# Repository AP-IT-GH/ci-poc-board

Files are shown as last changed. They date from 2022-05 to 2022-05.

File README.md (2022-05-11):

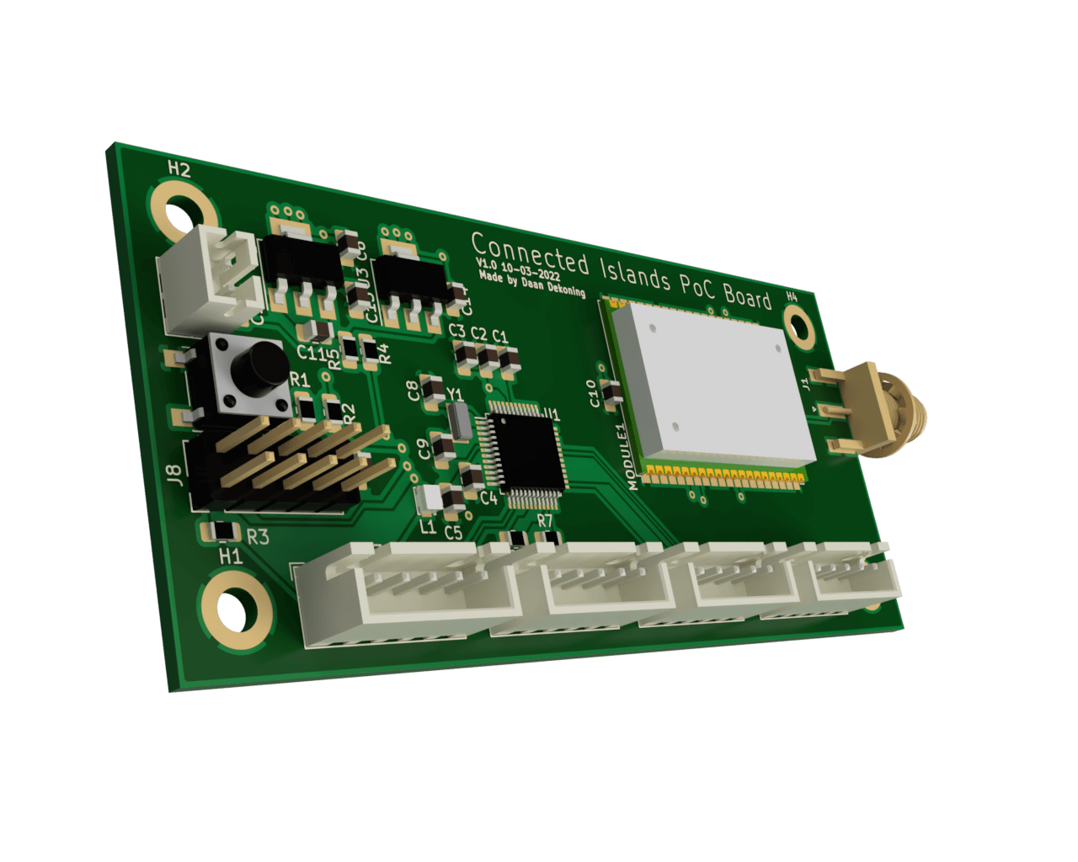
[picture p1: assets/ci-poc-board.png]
PCB


# Connected Island Proof of Concept Board

This board is used to gather data from many different sensors and send it over a LoRa network. 
The MCU on the board is an AT SAM D21 chosen because of it's low power capabilities and the extensive I/O options.
On board we have:
- 3 USART connection headers
- 1 I²C connection header
- 1 programming & debug connection
- RN2483 LoRaWAN module

The board can be powered with a voltage between 6.3V and 15V.

This document can be used to understand our reasoning behind certain choices and to learn how the board works. On the bottom we have a few improvements and suggestions for future versions.

The Bill of Materials to assemble the PCB can be found [here](./assets/bom/ibom.html) in HTML format.

## First Version

<figure>
<iframe src="https://myap84.autodesk360.com/shares/public/SH35dfcQT936092f0e434feaf45240fcc95f?mode=embed" width="1024" height="768" allowfullscreen="true" webkitallowfullscreen="true" mozallowfullscreen="true"  frameborder="0"></iframe>
<figcaption >Interactive 3D model of the PCB</figcaption>
</figure>

<figure>
Mindmap
<figcaption >Figure 1: Main Schematic</figcaption>
</figure>

<figure>
Mindmap
<figcaption >Figure 2: Power Regulators Schematic</figcaption>
</figure>

<figure>
Mindmap
<figcaption >Figure 3: RN2483 LoRaWAN module Schematic</figcaption>
</figure>

### Power Delivery

We are using a Li-Po 2 Cell battery and a LD1117 as 3.3V and 5V regulator

Li-Po 2 Cell: [Store](https://www.conrad.be/p/conrad-energy-lipo-accupack-74-v-2400-mah-aantal-cellen-2-20-c-softcase-xt60-1344133), [Datasheet](https://asset.conrad.com/media10/add/160267/c1/-/en/001344133SD01/veiligheidsvoorschriften-1344133-conrad-energy-lipo-accupack-74-v-2400-mah-aantal-cellen-2-20-c-sof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)

LD1117: [Store](https://www.conrad.be/p/stmicroelectronics-ld1117av33-spanningsregelaar-lineair-to-220ab-positief-vast-1-a-1184973), [Datasheet](https://asset.conrad.com/media10/add/160267/c1/-/en/001184973DS01/datablad-1184973-stmicroelectronics-ld1117av33-spanningsregelaar-lineair-to-220ab-positief-vast-1-a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)

The LD1117 IC's are connected according to "Figure 3. Application circuit (for fixed output voltages)". 1x 5V en 1x 3.3V.

The dropout voltage of these regulators is 1.05V if we're counting for a 500mAh load. to get an output voltage of 5V, the regulator needs an input voltage of 5V + 1.05V = 6.05V. Thus our battery voltage has to stay above that value.

ADC voltage divider for battery:

R1 = 10 kOhm; R2 = 4.7 kOhm

### AT SAMD 21 Schematic Checklist

Datasheet p1108-p1118

#### Power Supply Connections

- [x] Check L1 10µH footprint. (https://be.farnell.com/tdk/vls201612hbx-100m-1/inductor-10uh-20-0-79a-shld/dp/2455369 ) (https://www.farnell.com/datasheets/2608157.pdf )

The MCU has two DVVIO pins (pin17 en pin36), these are internally connected to each other so only pin17 is in use.

#### External Analog Reference Connections

Not necessary because we are not using any external analog references.

#### External Reset Circuit

EFT = electrical fast transients -> spark when pressing a button

We don't need this EFT Immunity Enhancement so we're using "Figure 45-4. External Reset Circuit Schematic".

#### Clocks and Crystal Oscillators

[Understanding the SAM D21 clocks](https://blog.thea.codes/understanding-the-sam-d21-clocks/)

We keep the option to use an external 32,768kHz clock free, when not in use it doesn't have to be soldered on the PCB.

- [Capacitor](https://be.farnell.com/multicomp/mc0805n180j500ct/cap-18pf-50v-5-c0g-np0-0805/dp/1759194): MC0805N180J500CT, 18 pF, 0805
- [Crystal](https://be.farnell.com/fox-electronics/fx135a-327/crystal-32-768khz-12-5pf-smd/dp/2064037): FX135A-327, 32.768 kHz, SMD

Connected according to: "Figure 45-9. External Real Time Oscillator with Load Capacitor".

`XIN32` and `XOUT32` are on the only available connections for SERCOM1 (PA00 en PA01) so SERCOM1 will not be used.

#### Programming and Debug Ports

Pull-up resistor on SWCLK!

We are using "Figure 45-12. 10-pin JTAGICE3 Compatible Serial Wire Debug Interface".

#### USB Interface

We are not using the USB interface.

### SERCOM Aansluiten

The used SERCOM pins of the SAM D21 got a `SERCOMx_PADn_y` label for easy reference on the scheme and PCB. The Atmel START configuration was used as a reference.

SERCOM-ALT [ref1](https://microchipsupport.force.com/s/article/SERCOM-muxing-on-SAM-D-L-C-devices), [ref2](https://learn.adafruit.com/using-atsamd21-sercom-to-add-more-spi-i2c-serial-ports/muxing-it-up)

| Use case | SERCOM  | Pins | Function |
| --- | --- | --- | --- |
| RN2384  | SERCOM0 | PA04, PA05, PA07 | TX, RX, <span style="text-decoration:overline">RESET</span> |
| USART_1 | SERCOM5 | PA22, PA23 | TX, RX |
| USART_2 | SERCOM2 | PA08, PA09 | TX, RX |
| USART_3 | SERCOM3 | PA16, PA17 | TX, RX |
| I2C_0 | SERCOM4 | PA12, PA13 | SDA, SCL |

> If the PA24 and PA25 pins are not connected, it is recommended to enable a pull-up on PA24 and PA25 through input GPIO mode. The aim is to avoid an eventually extract power consumption (<1mA) due to a not stable level on pad. The port PA24 and PA25 doesn't have Drive Strength option. (these are the USB pins). 

[ATSAMD D21 Datasheet](https://ww1.microchip.com/downloads/en/DeviceDoc/SAM-D21DA1-Family-Data-Sheet-DS40001882G.pdf)

### RN2483 LoRaWAN module

[RN2483 Datasheet](https://ww1.microchip.com/downloads/en/DeviceDoc/RN2483-Low-Power-Long-Range-LoRa-Technology-Transceiver-Module-DS50002346F.pdf) 

Reuse of symbol from the older AirQualitySensor project.

`PA6` who is connected to `RN2384_RESET` should always be HIGH. You can reset the RN2483 module by setting the pin LOW for a moment.

<u>Are we using `UART_CTS` and `UART_RTS` as a handshake mechanism?</u>: No

<u>Do we connect the Internal Program Pins with the 6-pin ICSP header on our PCB?</u>: No

We are using RFH for 868MHz communication.

> When routing RF paths, use proper strip lines with an impedance of 50 Ohm.

We are not using the GPIO pins of the module.

## Future Versions

Luckily, the first version of this board works. Of course we have a few remarks to make for future versions of this board. 
A short summary:
- More marks on the silkscreen explaining the pinout of headers
- A different battery connector
- Adding a USB port
- Placing components on the back

### Markings

The first version of the board doesn't show any markings for the pinout of the headers. The battery connector doesn't even have a polarity marking. 

### Battery Connector

The current battery connector is very small and not very useful. A specific new connector has not been chosen yet.

### USB Port

We think that a USB port on the PCB would be very useful. There exists a bootloader for the ATSAMD 21 that enables users to program the board with CircuitPython. This might make the board easier to use. Other bootloaders enable the use of the Arduino IDE instead of Microchip Studio. 
Right now the board can only be programmed with a J-LINK or Atmel ICE programmer. 

### Components on the Back

Right now every component on the board is positioned on the front. We think a lot of space can be saved by placing some SMD components on the back.

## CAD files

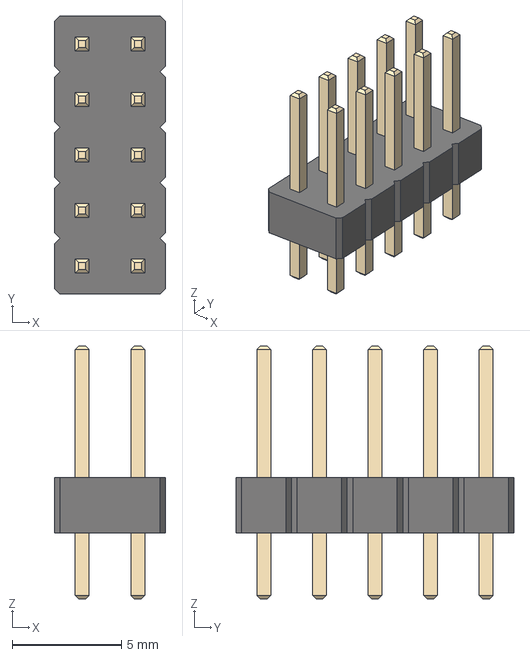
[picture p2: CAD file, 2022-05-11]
3d_models/PinHeader_2x05_P2.54mm_Vertical.step
5.08 x 12.7 x 11.5 mm

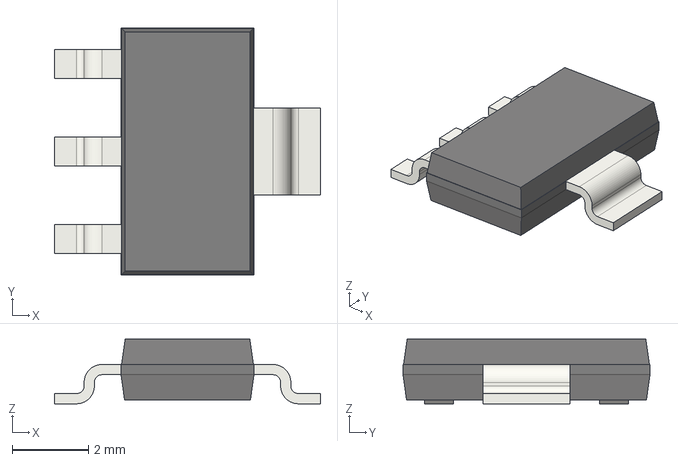
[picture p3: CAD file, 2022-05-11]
3d_models/SOT-223.step
7.00 x 6.50 x 1.70 mm

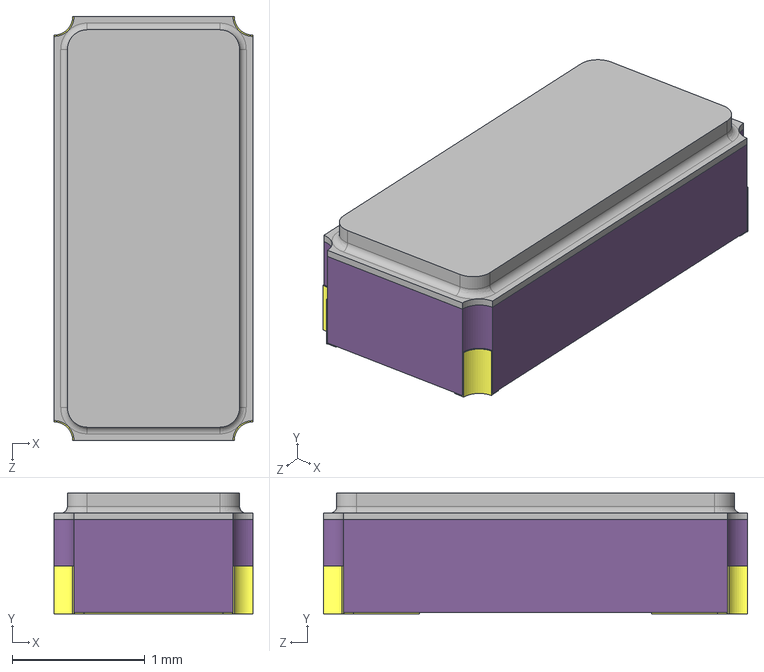
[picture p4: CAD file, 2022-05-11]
3d_models/User Library-FX135A-327.step
1.50 x 0.91 x 3.20 mm

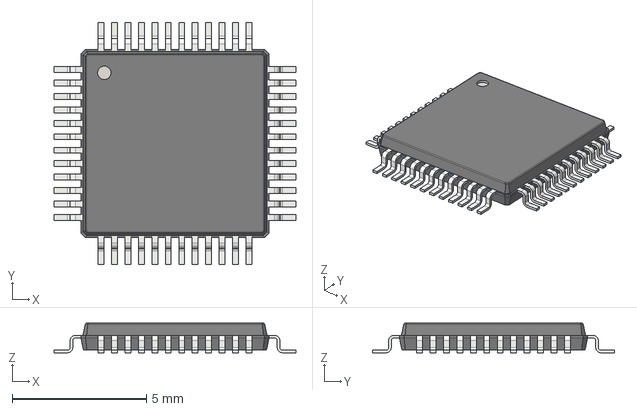
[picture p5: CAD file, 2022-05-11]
3d_models/TQFP-48_7x7mm_P0.5mm.step
9.00 x 9.00 x 1.10 mm

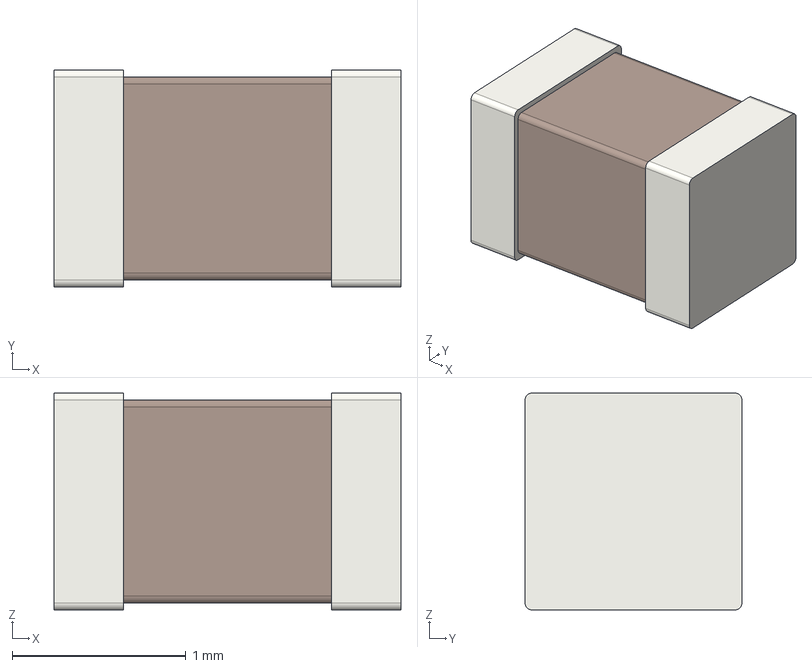
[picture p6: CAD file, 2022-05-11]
3d_models/C_0805_2012Metric.step
2.00 x 1.25 x 1.25 mm

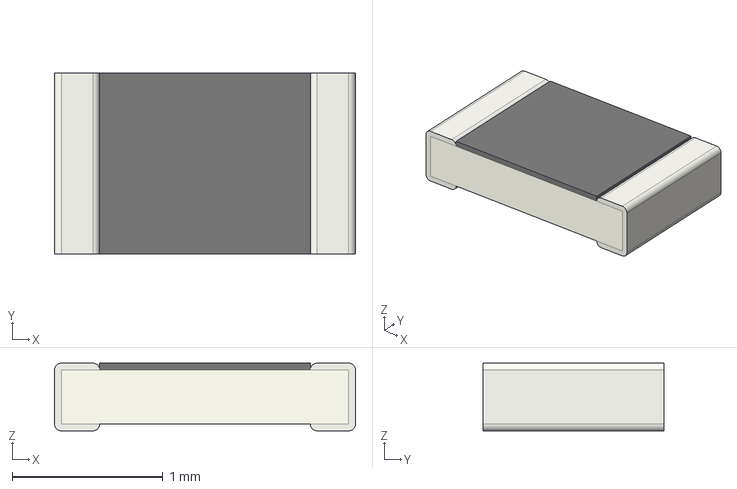
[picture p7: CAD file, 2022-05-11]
3d_models/R_0805_2012Metric.step
2.00 x 1.20 x 0.45 mm

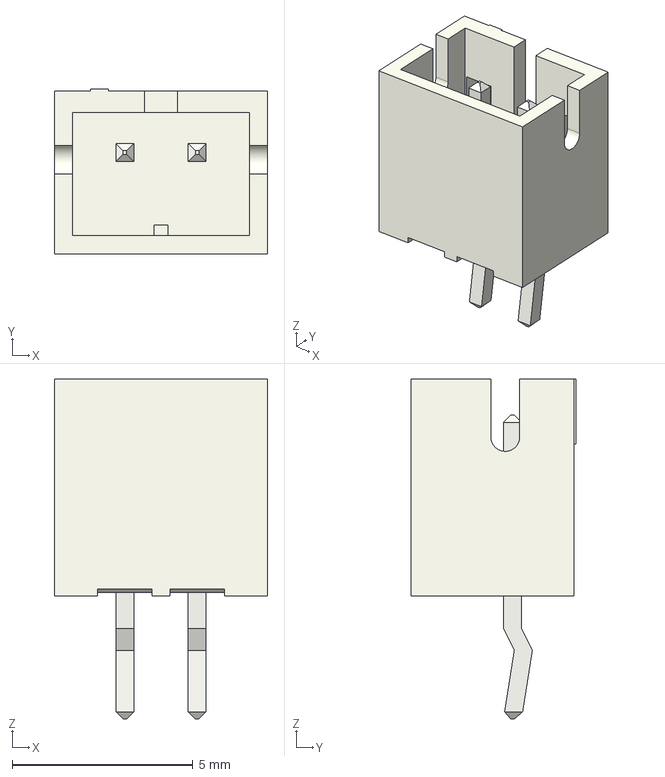
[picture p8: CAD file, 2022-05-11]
3d_models/JST_PH_B2B-PH-K_1x02_P2.00mm_Vertical.step
5.90 x 4.55 x 9.40 mm

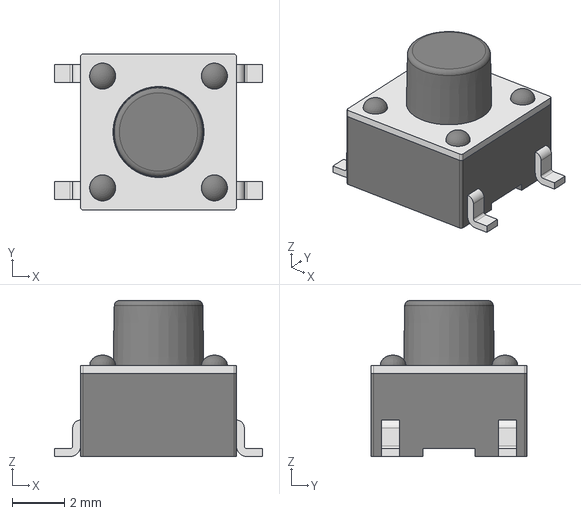
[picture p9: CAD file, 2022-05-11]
3d_models/TS6-SMT_H-6.0.step
8.00 x 6.00 x 6.00 mm

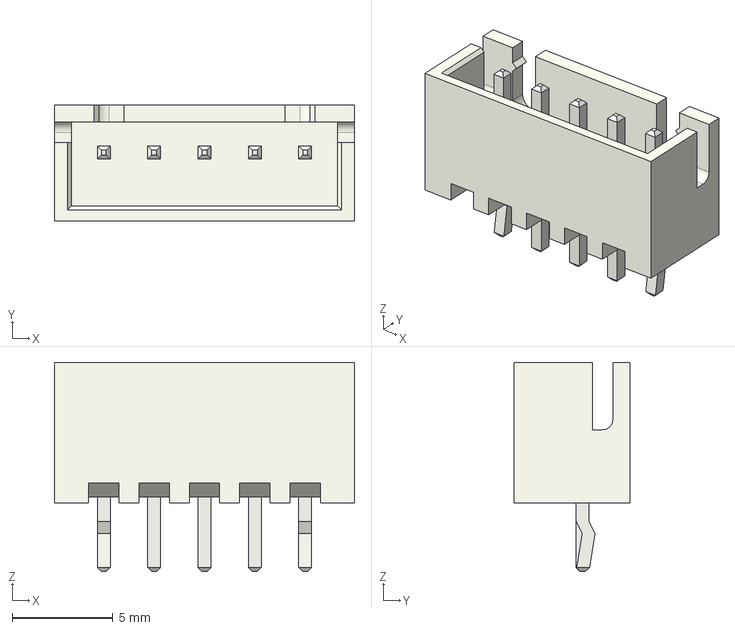
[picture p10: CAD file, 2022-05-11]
3d_models/JST_XH_B5B-XH-A_1x05_P2.50mm_Vertical.step
14.9 x 5.75 x 10.4 mm

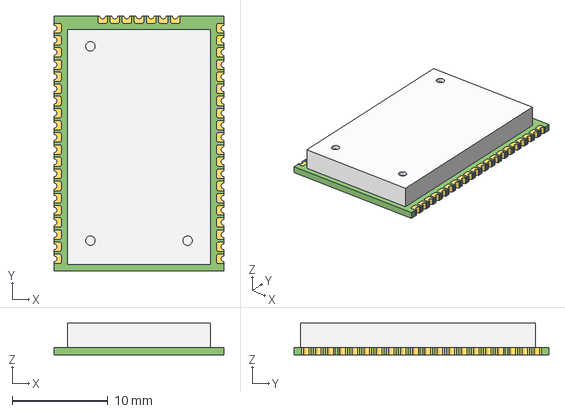
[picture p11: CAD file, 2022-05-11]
3d_models/RN2483.step
17.8 x 26.7 x 3.34 mm

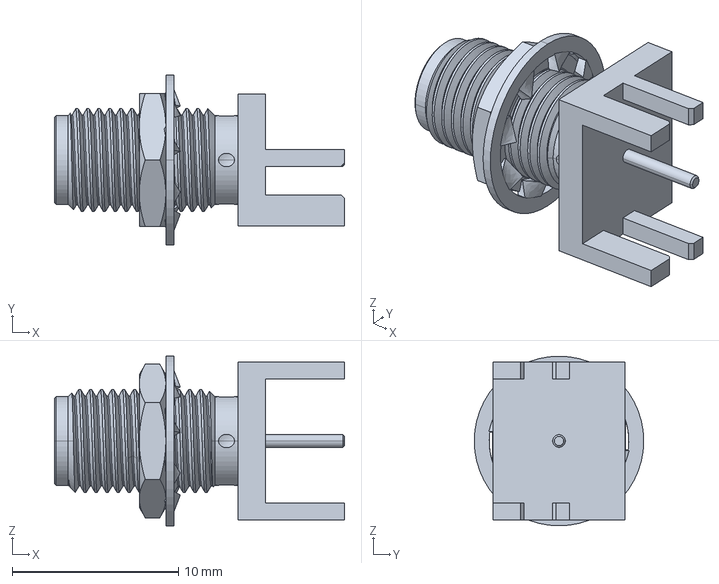
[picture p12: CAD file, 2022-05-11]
3d_models/132289.stp
17.4 x 10.2 x 10.2 mm

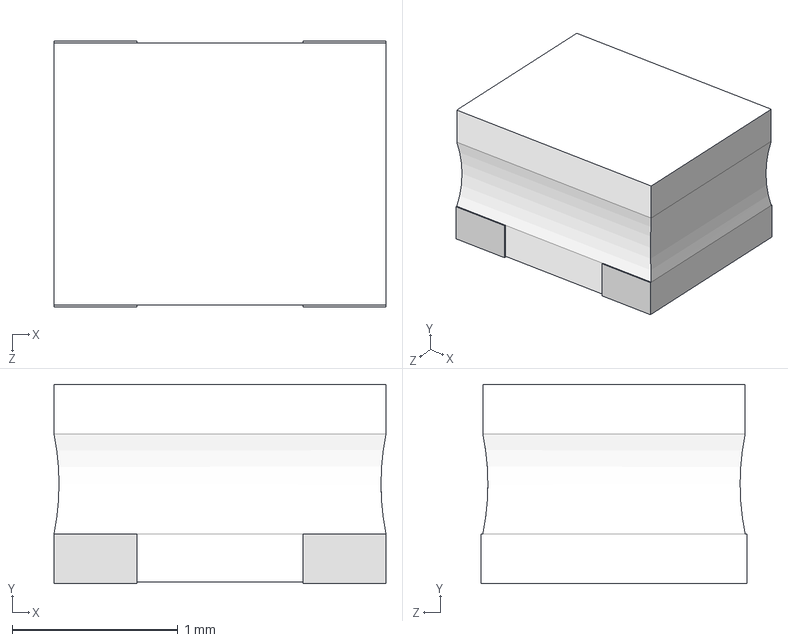
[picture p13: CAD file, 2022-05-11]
3d_models/vls201612hbx-1.step
2.00 x 1.20 x 1.60 mm

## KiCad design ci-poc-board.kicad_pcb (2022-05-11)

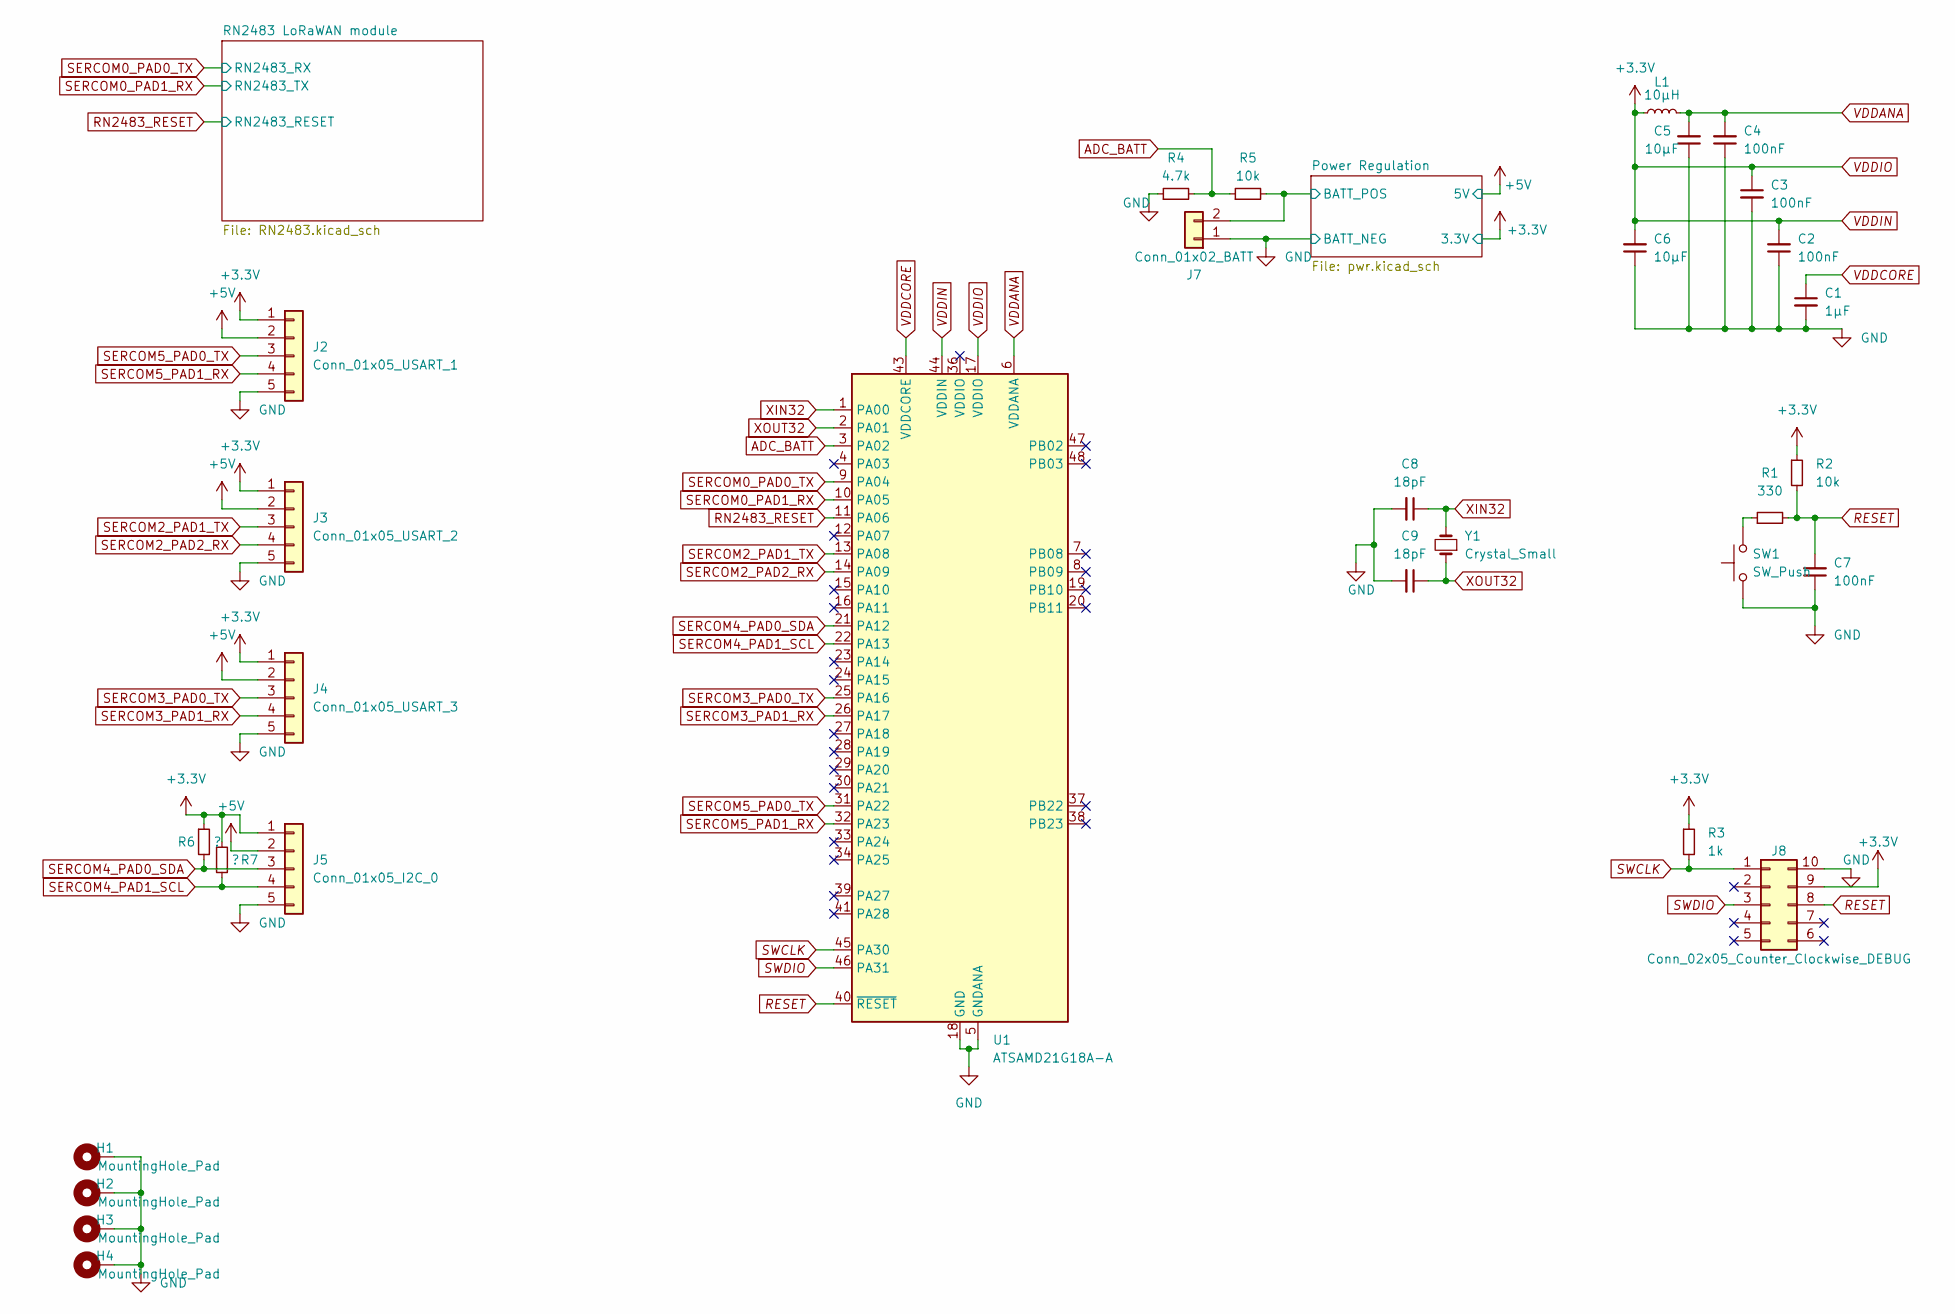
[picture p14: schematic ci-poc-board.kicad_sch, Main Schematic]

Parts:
C1: 1µF; C_0805_2012Metric_Pad1.18x1.45mm_HandSolder
C2, C3, C4, C7: 100nF; C_0805_2012Metric_Pad1.18x1.45mm_HandSolder
C5, C6: 10µF; C_0805_2012Metric_Pad1.18x1.45mm_HandSolder
C8, C9: 18pF; C_0805_2012Metric_Pad1.18x1.45mm_HandSolder
H1, H2, H3, H4: MountingHole_Pad; MountingHole_3.2mm_M3_DIN965_Pad
J2: Conn_01x05_USART_1; JST_XH_B5B-XH-A_1x05_P2.50mm_Vertical
J3: Conn_01x05_USART_2; JST_XH_B5B-XH-A_1x05_P2.50mm_Vertical
J4: Conn_01x05_USART_3; JST_XH_B5B-XH-A_1x05_P2.50mm_Vertical
J5: Conn_01x05_I2C_0; JST_XH_B5B-XH-A_1x05_P2.50mm_Vertical
J7: Conn_01x02_BATT; JST_PH_B2B-PH-K_1x02_P2.00mm_Vertical
J8: Conn_02x05_Counter_Clockwise_DEBUG; PinHeader_2x05_P2.54mm_Vertical
L1: 10µH; L_Murata_LQH2MCNxxxx02_2.0x1.6mm
R1: 330; R_0805_2012Metric_Pad1.20x1.40mm_HandSolder
R2, R5: 10k; R_0805_2012Metric_Pad1.20x1.40mm_HandSolder
R3: 1k; R_0805_2012Metric_Pad1.20x1.40mm_HandSolder
R4: 4.7k; R_0805_2012Metric_Pad1.20x1.40mm_HandSolder
R6, R7: ?; R_0805_2012Metric_Pad1.20x1.40mm_HandSolder
SW1: SW_Push; SW_Push_1P1T_NO_6x6mm_H9.5mm
U1: ATSAMD21G18A-A; TQFP-48_7x7mm_P0.5mm
Y1: Crystal_Small; Crystal_SMD_3215-2Pin_3.2x1.5mm

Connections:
+5V: J2.2, J3.2, J4.2, J5.2; also elsewhere on the board
/Power Regulation/BATT_POS: J7.2, R5.2; also elsewhere on the board
ADC_BATT: R4.2, R5.1, U1.3 (PA02)
GND: C1.2, C2.1, C3.2, C4.1, C5.1, C6.1, C7.1, C8.2, C9.2, H1.1, H2.1, H3.1, H4.1, J2.5, J3.5, J4.5, J5.5, J7.1, J8.10, R4.1, SW1.2, U1.5 (GNDANA), U1.18 (GND), U1.35 (GND), U1.42 (GND); also elsewhere on the board
unnamed: R1.1, SW1.1
RESET: C7.2, J8.8, R1.2, R2.2, U1.40 (~RESET)
RN2483_RESET: U1.11 (PA06); also elsewhere on the board
SERCOM0_PAD0_TX: U1.9 (PA04); also elsewhere on the board
SERCOM0_PAD1_RX: U1.10 (PA05); also elsewhere on the board
SERCOM2_PAD1_TX: J3.3, U1.13 (PA08)
SERCOM2_PAD2_RX: J3.4, U1.14 (PA09)
SERCOM3_PAD0_TX: J4.3, U1.25 (PA16)
SERCOM3_PAD1_RX: J4.4, U1.26 (PA17)
SERCOM4_PAD0_SDA: J5.3, R6.2, U1.21 (PA12)
SERCOM4_PAD1_SCL: J5.4, R7.2, U1.22 (PA13)
SERCOM5_PAD0_TX: J2.3, U1.31 (PA22)
SERCOM5_PAD1_RX: J2.4, U1.32 (PA23)
SWCLK: J8.1, R3.2, U1.45 (PA30)
SWDIO: J8.3, U1.46 (PA31)
VDDANA: C4.2, C5.2, L1.2, U1.6 (VDDANA)
VDDCORE: C1.1, U1.43 (VDDCORE)
VDDIN: C2.2, C3.1, C6.2, J2.1, J3.1, J4.1, J5.1, J8.9, L1.1, R2.1, R3.1, R6.1, R7.1, U1.17 (VDDIO), U1.44 (VDDIN); also elsewhere on the board
XIN32: C8.1, U1.1 (PA00), Y1.2
XOUT32: C9.1, U1.2 (PA01), Y1.1

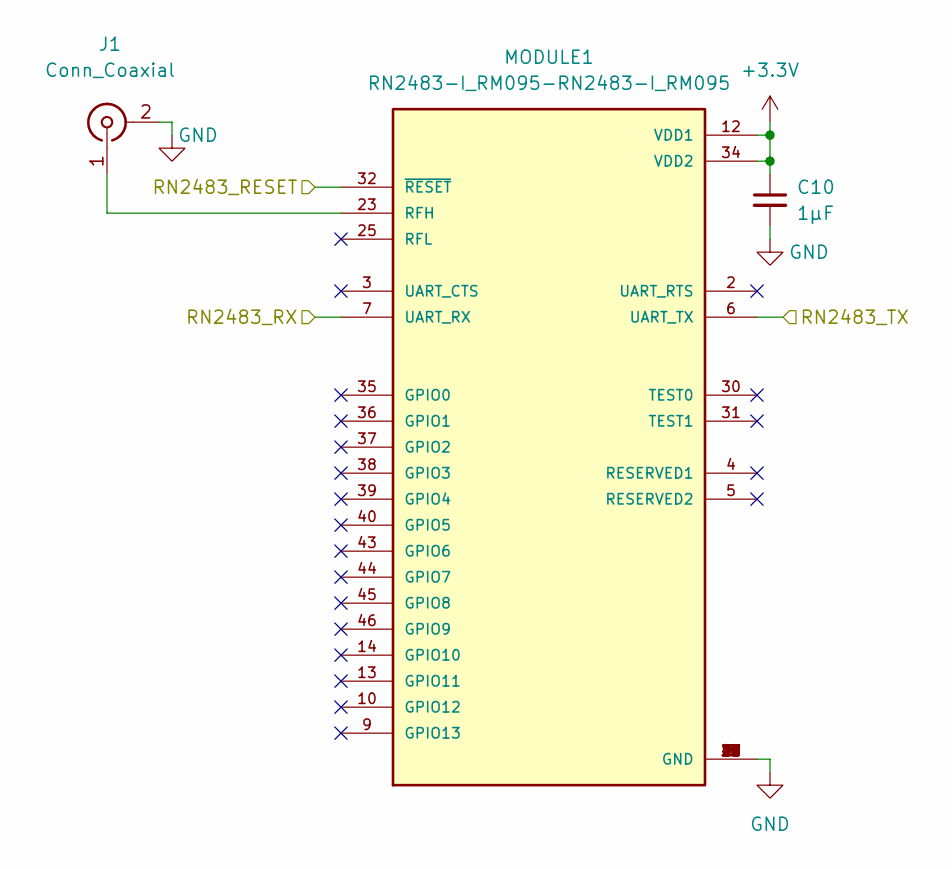
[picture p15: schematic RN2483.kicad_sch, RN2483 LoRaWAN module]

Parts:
C10: 1µF; C_0805_2012Metric_Pad1.18x1.45mm_HandSolder
J1: Conn_Coaxial; SMA_Amphenol_132289_EdgeMount
MODULE1: RN2483-I_RM095-RN2483-I_RM095; RN2483

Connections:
GND: C10.2, J1.2 (Ext), MODULE1.1 (GND), MODULE1.8 (GND), MODULE1.11 (GND), MODULE1.20 (GND), MODULE1.21 (GND), MODULE1.22 (GND), MODULE1.24 (GND), MODULE1.26 (GND), MODULE1.27 (GND), MODULE1.28 (GND), MODULE1.33 (GND), MODULE1.41 (GND), MODULE1.47 (GND); also elsewhere on the board
unnamed: J1.1 (In), MODULE1.23 (RFH)
RN2483_RESET: MODULE1.32 (~RESET); also elsewhere on the board
SERCOM0_PAD0_TX: MODULE1.7 (UART_RX); also elsewhere on the board
SERCOM0_PAD1_RX: MODULE1.6 (UART_TX); also elsewhere on the board
VDDIN: C10.1, MODULE1.12 (VDD1), MODULE1.34 (VDD2); also elsewhere on the board

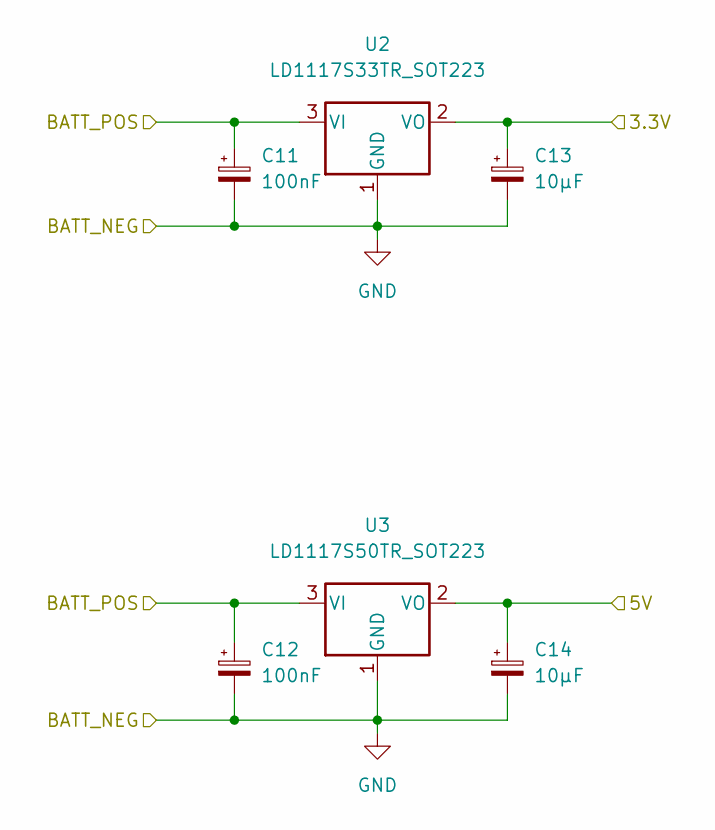
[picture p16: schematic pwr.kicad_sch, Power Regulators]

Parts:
C11, C12: 100nF; C_0805_2012Metric_Pad1.18x1.45mm_HandSolder
C13, C14: 10µF; C_0805_2012Metric_Pad1.18x1.45mm_HandSolder
U2: LD1117S33TR_SOT223; SOT-223-3_TabPin2
U3: LD1117S50TR_SOT223; SOT-223-3_TabPin2

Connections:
+5V: C14.1, U3.2 (VO); also elsewhere on the board
/Power Regulation/BATT_POS: C11.1, C12.1, U2.3 (VI), U3.3 (VI); also elsewhere on the board
GND: C11.2, C12.2, C13.2, C14.2, U2.1 (GND), U3.1 (GND); also elsewhere on the board
VDDIN: C13.1, U2.2 (VO); also elsewhere on the board

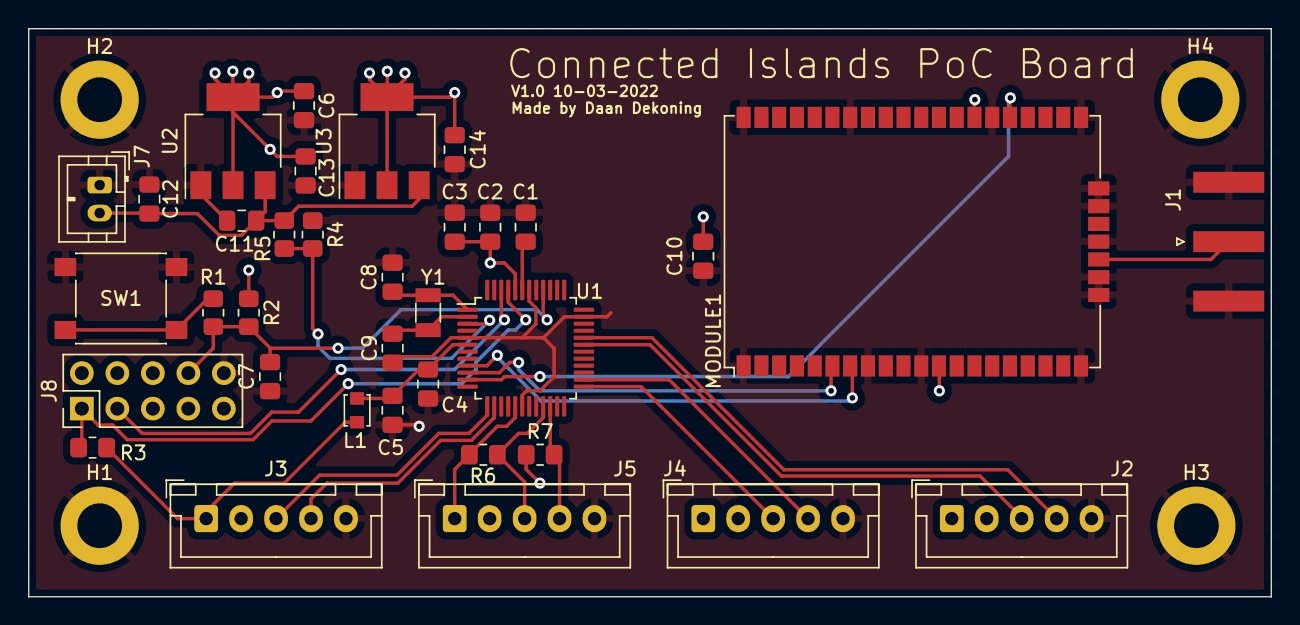
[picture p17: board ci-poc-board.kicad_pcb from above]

Board: 4 copper layers, 88.9 x 40.6 mm, 39 parts (0 on the bottom side), 25 nets.

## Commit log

2022-02-14 initial commit v1
    [ci-poc-board.kicad_pcb, ci-poc-board.kicad_sch]
2022-02-14 USART, SPI en I2C connecties gemaakt. OSC toegevoegd. JTAG ICE compatible interface toegevoegd.
    [ci-poc-board.kicad_sch]
2022-02-16 Added RN2483 LoRa Module, battery connection, oscillator, 3.3V and 5V regulator. Removed SPI
    [RN2483.kicad_sch, ci-poc-board.kicad_sch, pwr.kicad_sch]
2022-02-28 Finishing schematic, first iteration of PCB
    [RN2483.kicad_sch, ci-poc-board.kicad_pcb, ci-poc-board.kicad_sch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]
2022-03-04 Moved SMA connector to the edge
    [ci-poc-board.kicad_pcb, ci-poc-board.kicad_sch, pwr.kicad_sch]
2022-03-09 Small changes. Added BOM
    [RN2483.kicad_sch, ci-poc-board.kicad_pcb, ci-poc-board.kicad_sch]
2022-03-10 Added title and date to PCB, added render to README.md
    [ci-poc-board.kicad_pcb]
2022-05-11 Edited documentation
    [RN2483.kicad_sch, ci-poc-board.kicad_pcb, ci-poc-board.kicad_sch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]
2022-05-11 Make KiCad project more portable
    [132289.stp, C_0805_2012Metric.step, JST_PH_B2B-PH-K_1x02_P2.00mm_Vertical.step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]

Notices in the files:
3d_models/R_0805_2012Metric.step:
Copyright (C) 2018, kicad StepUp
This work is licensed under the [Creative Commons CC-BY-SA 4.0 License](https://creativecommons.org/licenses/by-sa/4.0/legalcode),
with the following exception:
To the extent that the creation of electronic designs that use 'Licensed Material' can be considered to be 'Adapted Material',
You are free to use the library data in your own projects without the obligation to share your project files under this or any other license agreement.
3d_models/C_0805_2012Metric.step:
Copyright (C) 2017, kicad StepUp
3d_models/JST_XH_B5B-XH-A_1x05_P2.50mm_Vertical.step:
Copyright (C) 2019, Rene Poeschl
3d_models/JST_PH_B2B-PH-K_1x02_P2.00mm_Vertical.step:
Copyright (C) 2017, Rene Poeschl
